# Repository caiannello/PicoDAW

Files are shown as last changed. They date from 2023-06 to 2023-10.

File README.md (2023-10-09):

# PicoDAW
A portable music sequencer and sampler based on Raspberry Pi Pico.  

WORK IN PROGRESS. 

There's no software yet! Also, I'm hoping that the SDIO SD Card interface is fast enough to stream
some audio tracks, since the Pico only has around 264KB or RAM. :D  We'll see.

I have code in the Pico and keyboard MCU to test the switches and LCD. Lots of diodes
need to be refitted, but progress is slowly being made. It is not yet able to make
any sounds.  

(Mockup screen borrowed from the MilkyTracker project. Just a static image..)
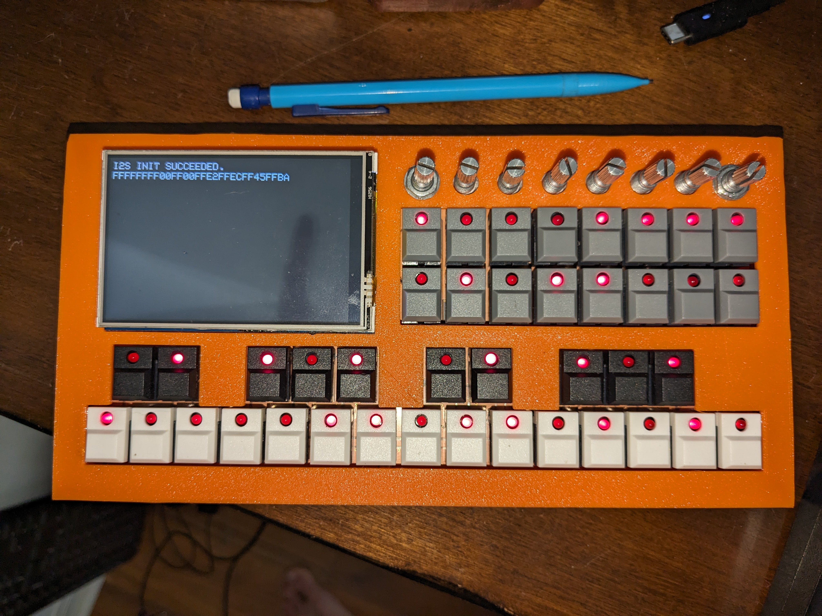
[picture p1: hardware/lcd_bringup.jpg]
LCD bring-up


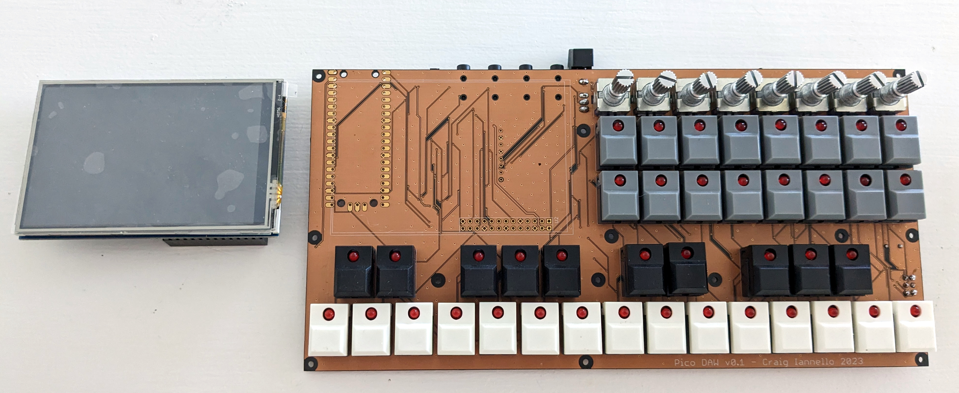
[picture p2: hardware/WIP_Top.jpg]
top

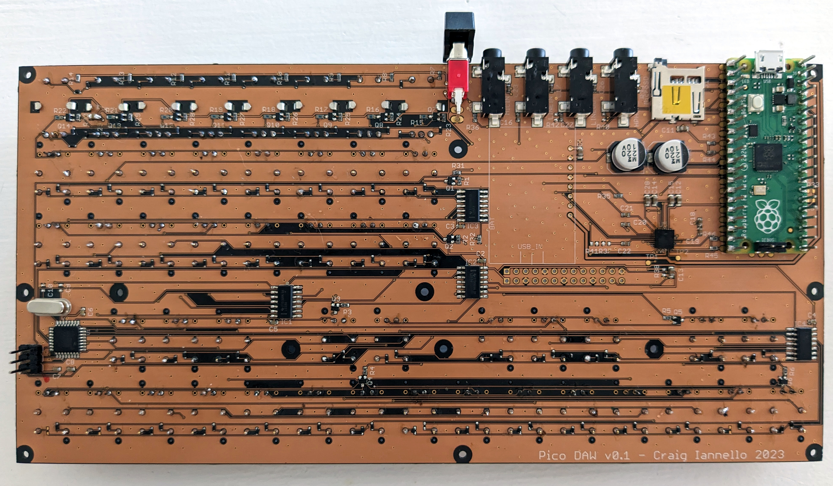
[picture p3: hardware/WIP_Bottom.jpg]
bottom


Velocity Sensitivity Note:

The keyswitches are quite clicky. They are HONYONE PB86 with integrated LED. Because the switches are SPDT Single-Pole-Double-Throw,
there is a possibility of timing the switch's break-before-make to get velocity information.  

That's why both throws on each switch are connected in the key matrix. 102 tiny little diodes.
During testing though, the clicky-ness of the keys causes this feature to not work very well. 

I tried anneling the switch's spring with heat, but that was a fail. 

Maybe someday I'll find some more suitable SPDT switches, but at least these ones look really cool!

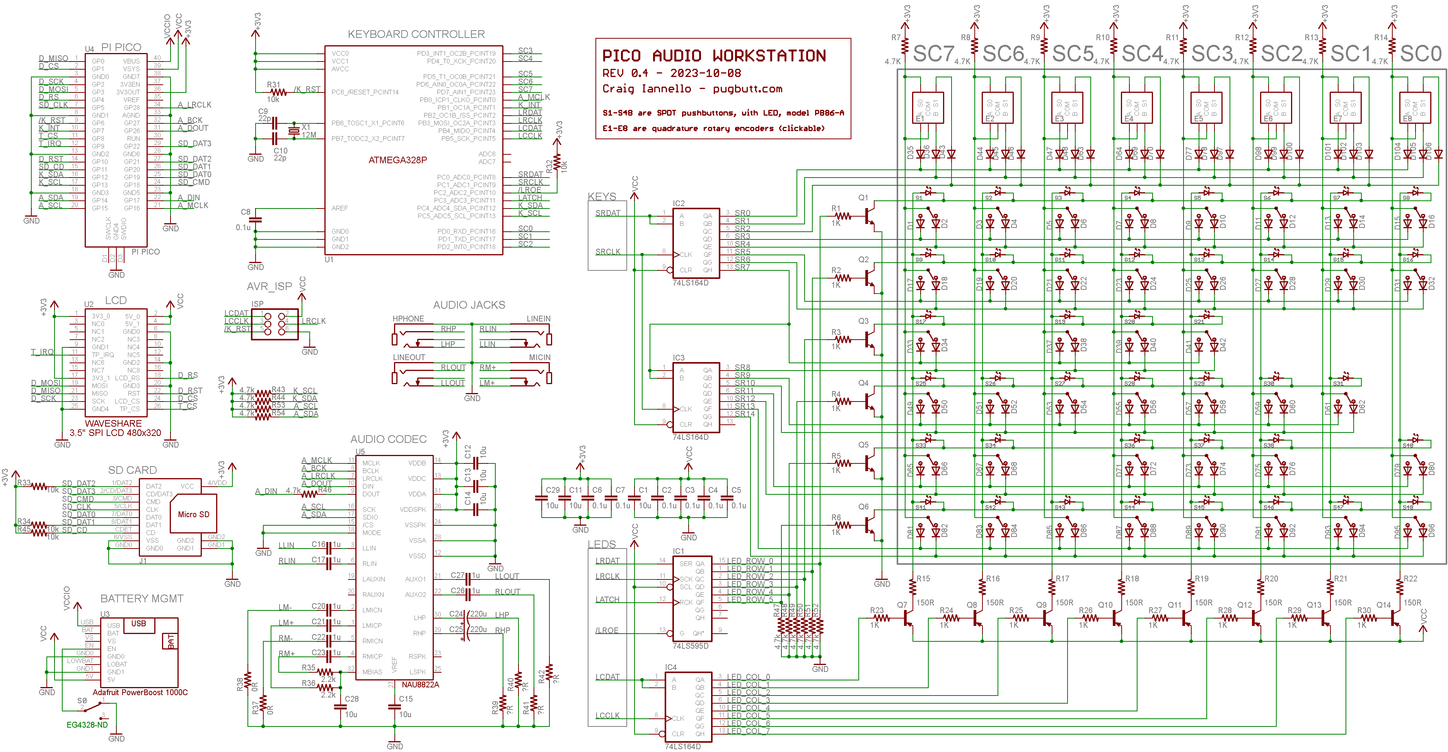
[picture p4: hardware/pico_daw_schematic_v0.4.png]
schematic

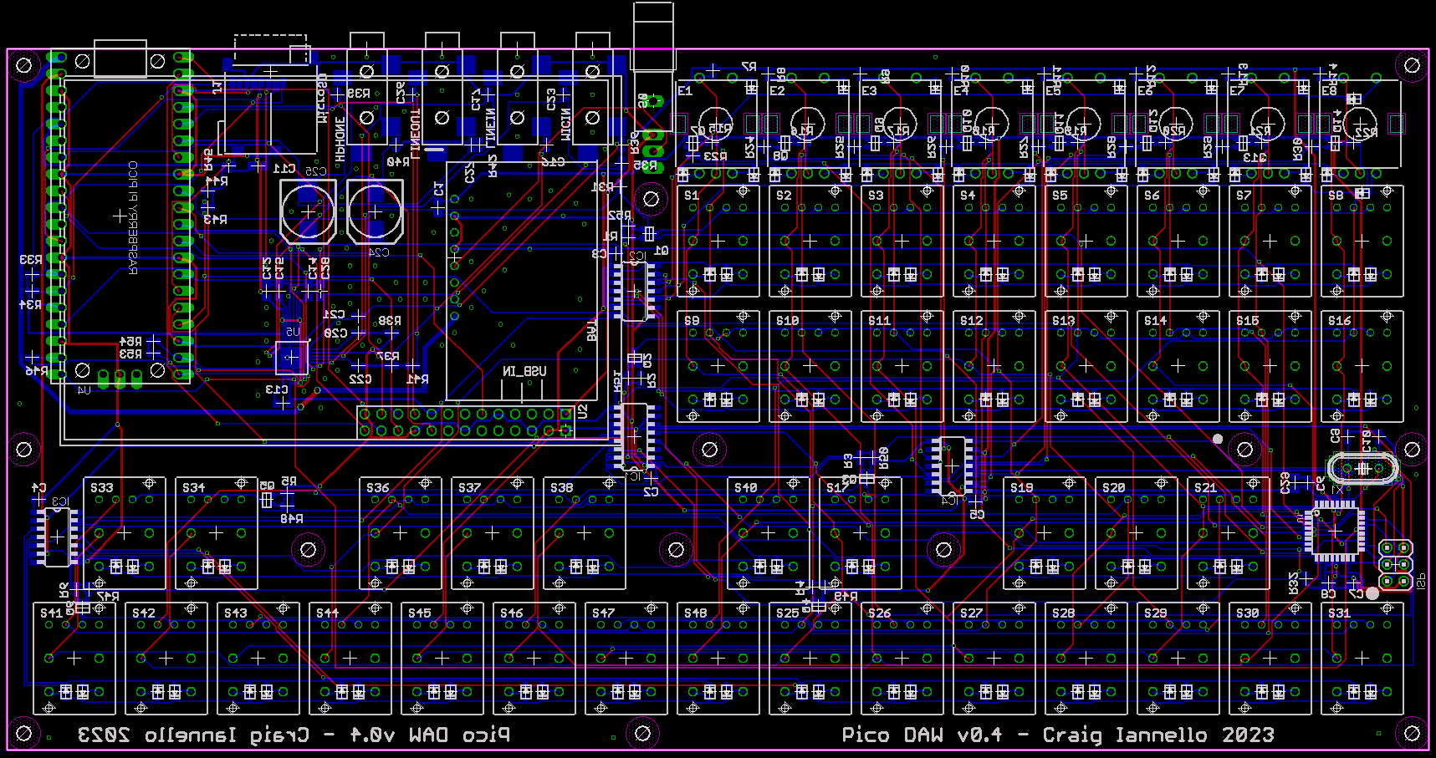
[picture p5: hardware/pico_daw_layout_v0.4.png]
layout


I've modelled a case and ordered it on Craftcloud.

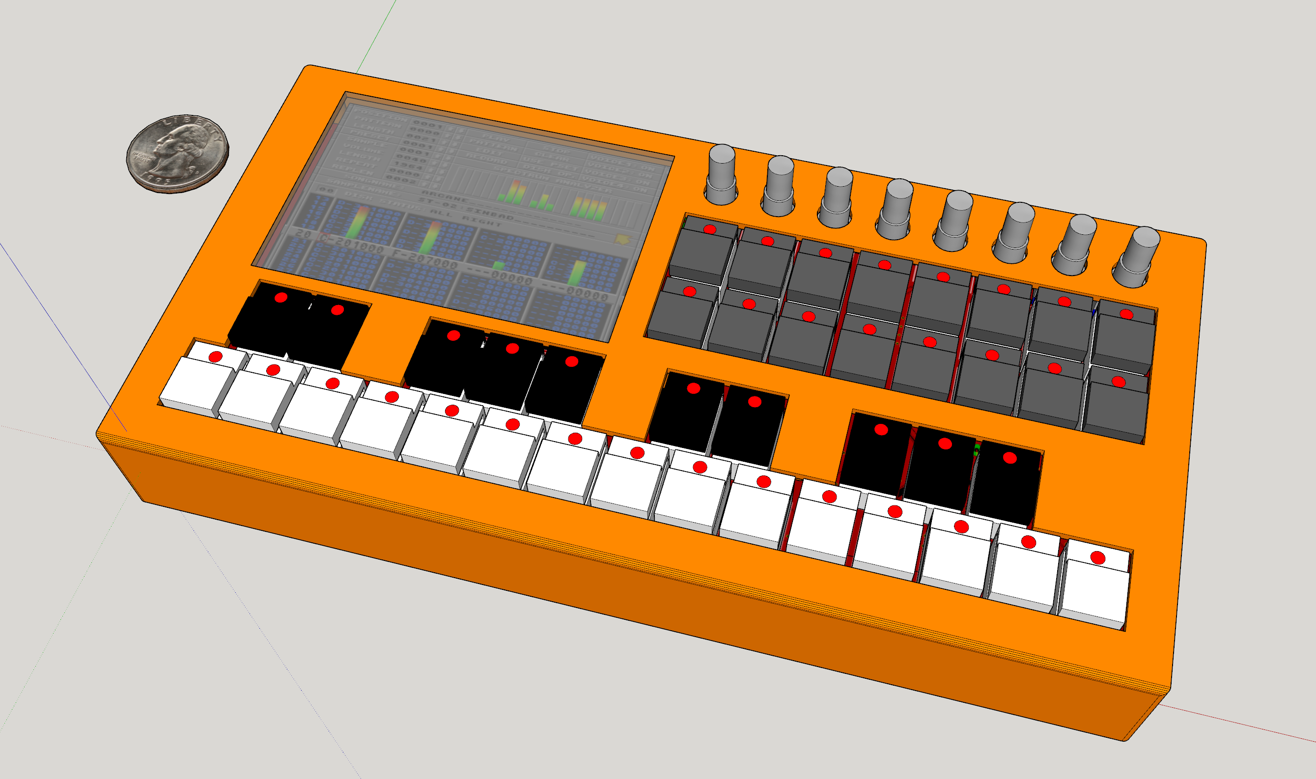
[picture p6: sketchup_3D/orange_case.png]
case design


Let's have an animated GIF on this page like its 1995!!

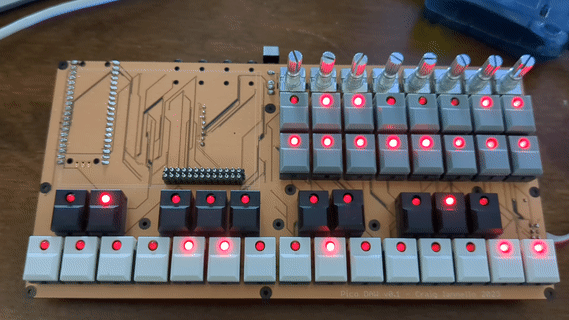
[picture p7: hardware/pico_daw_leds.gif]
blinky


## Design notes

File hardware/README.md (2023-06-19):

The schematic and board were made in Cadsoft EAGLE v4.16r2.

(I need to learn KiCAD someday.)

WARNING: TO PREVENT MAGIC SMOKE, REMOVE THE POWER DIODE FROM THE PI PICO !!!

This is because the battery board outputs it's own 5V, which runs to 
Vsys on the PI, and it and it receives its 5V charging voltage from the Pi's
Vusb.  (These two rails need to be decoupled on the Pi board.)

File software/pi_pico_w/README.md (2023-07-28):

So far, the Pi Pico code is just a switch / LCD test, with an attempt at a tone generator.

Note, this Arduino project uses the excellent gfx library, [TFT_eSPI, by Bodmer.](https://github.com/Bodmer/TFT_eSPI)

Before compiling, you have to customize one file of the library to reflect the GPIO connections to the LCD. (I tried defining them in my project, but I was unsuccessful.)

In "Arduino/libraries/TFT_eSPI-master/User_setup.h":
```
#define USER_SETUP_INFO "User_Setup"
#define RPI_ILI9486_DRIVER

#define TFT_SPI_PORT  0
#define TFT_MISO      0   // Automatically assigned with ESP8266 if not defined
#define TFT_MOSI      3   // Automatically assigned with ESP8266 if not defined
#define TFT_SCLK      2   // Automatically assigned with ESP8266 if not defined
#define TFT_CS        1   // Chip select control pin D8
#define TFT_DC        4   // Data Command control pin
#define TFT_RST       12  // Reset pin (could connect to NodeMCU RST, see next line)
#define TOUCH_CS      8   // Chip select pin (T_CS) of touch screen

#define SPI_FREQUENCY  27000000
#define SPI_READ_FREQUENCY  20000000
```
Note the 27MHz SPI clock speed. If you experience graphical glitches, try lowering that value.

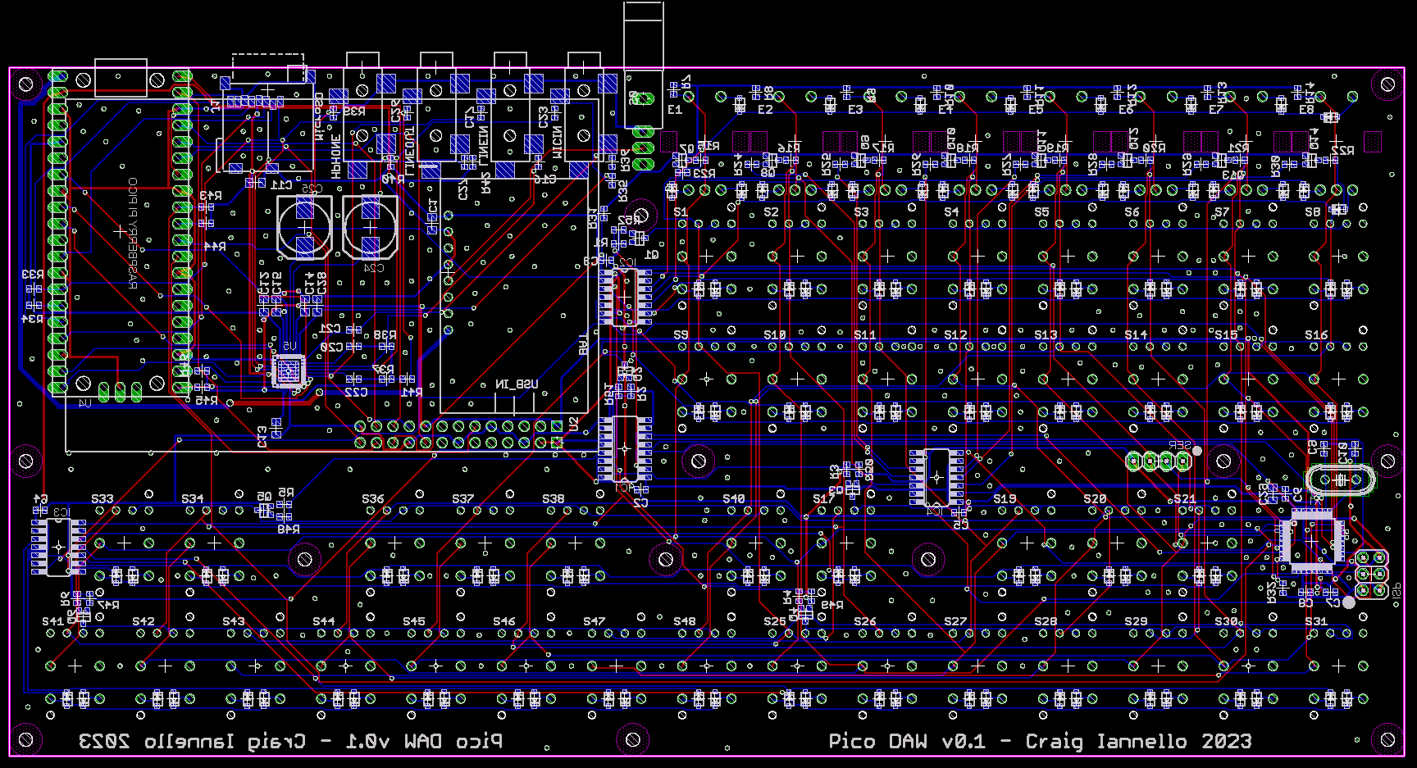
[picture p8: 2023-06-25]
hardware/pico_daw_layout_v0.1.png

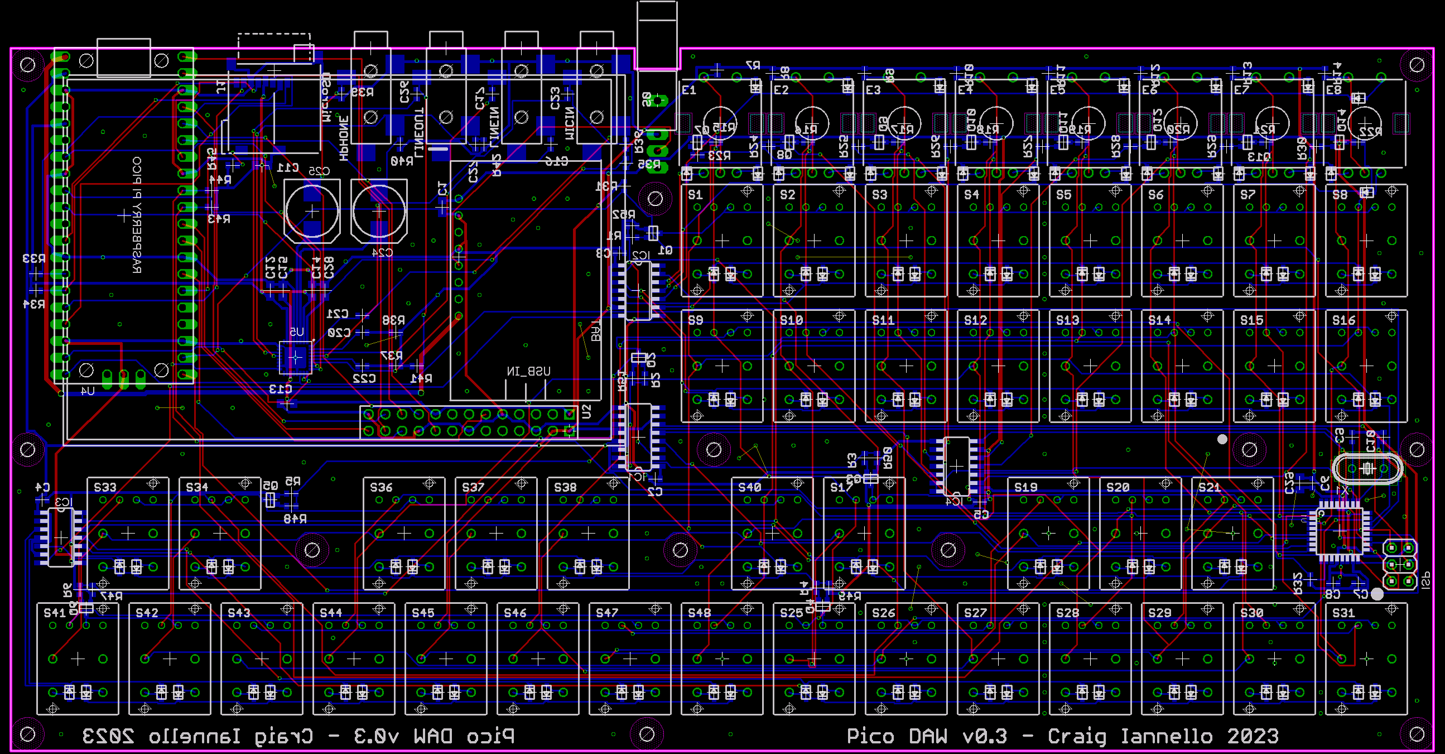
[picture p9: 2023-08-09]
hardware/pico_daw_layout_v0.3.png

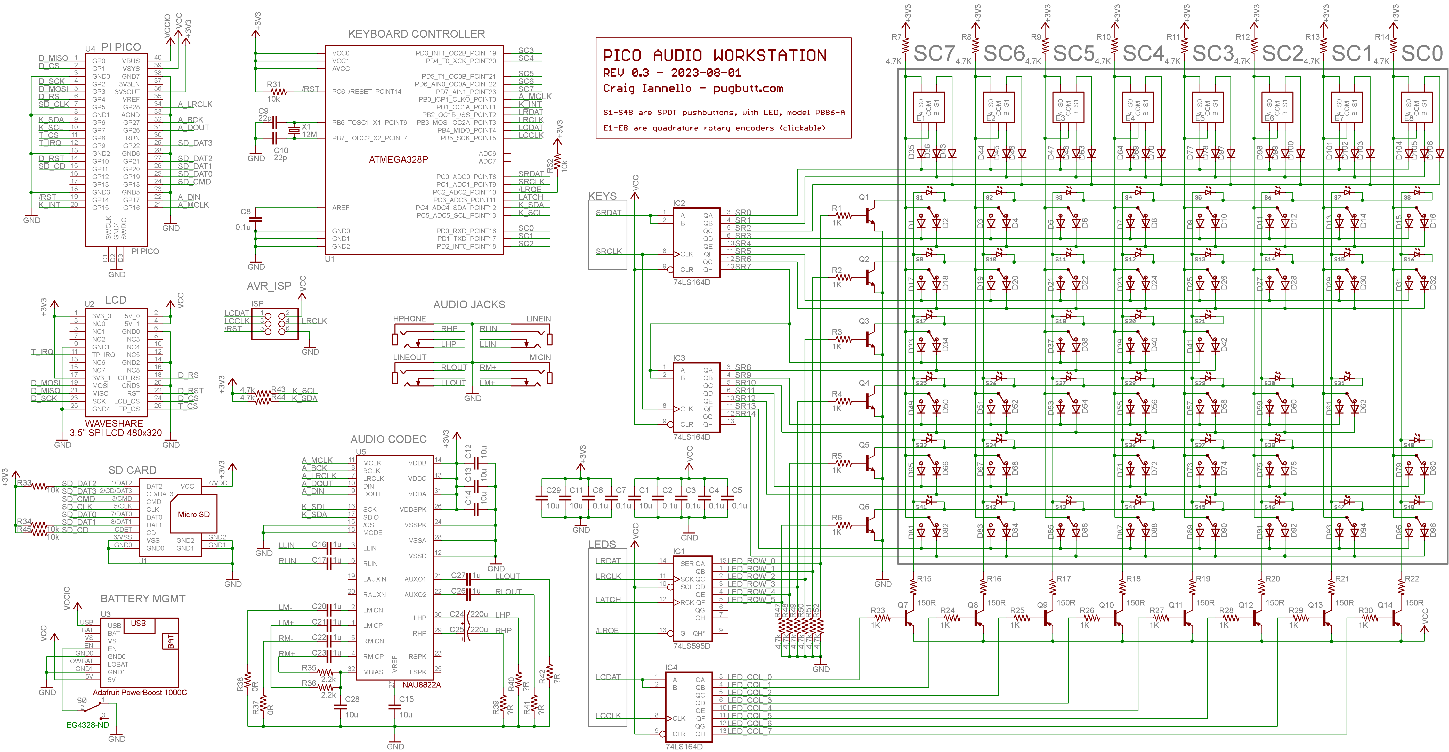
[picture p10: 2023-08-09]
hardware/pico_daw_schematic_v0.3.png

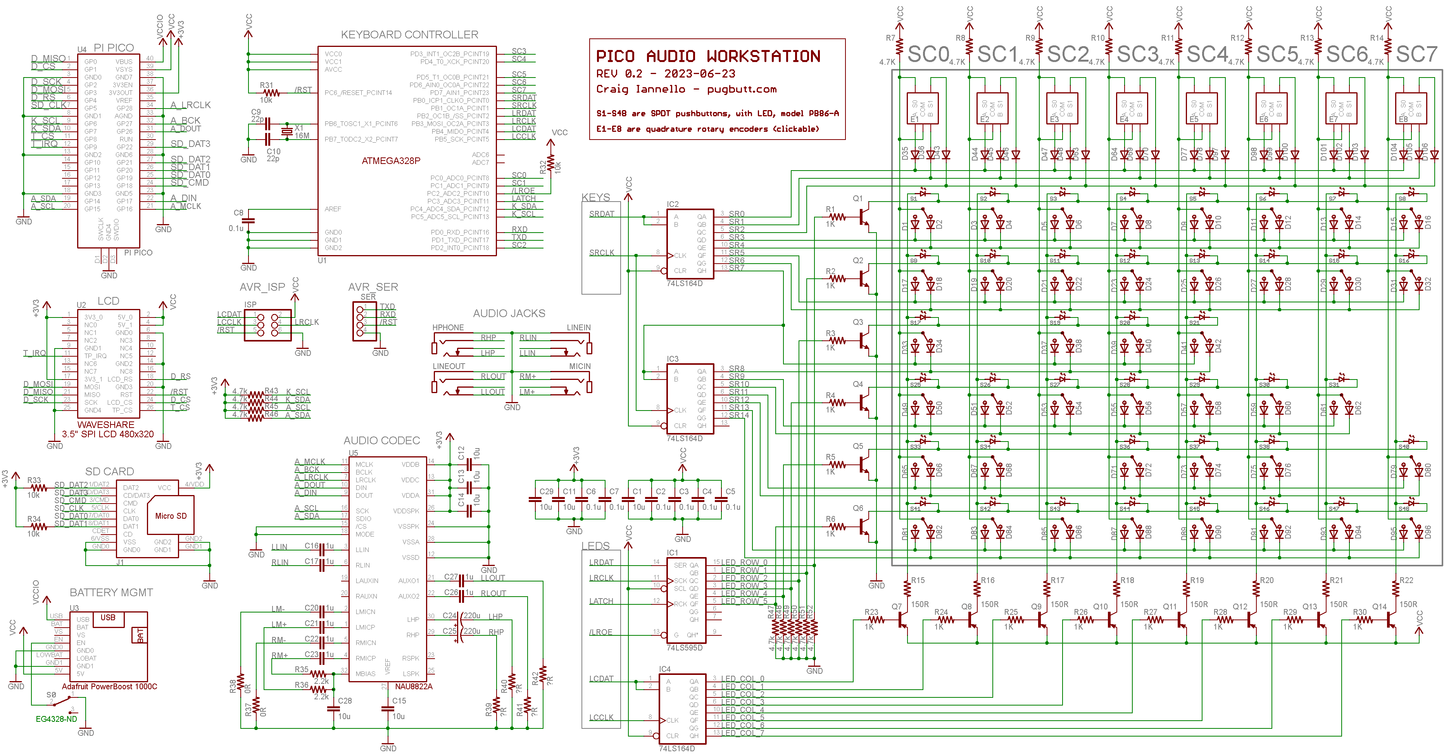
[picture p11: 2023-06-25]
hardware/pico_daw_schematic_v0.1.png

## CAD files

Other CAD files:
sketchup_3D/pico_daw_0.2.skp
sketchup_3D/pico_daw_0.3.skp
sketchup_3D/pico_daw_0.3_x_glitchy_sketchup.skp

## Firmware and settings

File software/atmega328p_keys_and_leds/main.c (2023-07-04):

///////////////////////////////////////////////////////////////////////////////
//
// atmega328p_keys_and_leds.c
//
// This is the firmware for the little ATMEGA328P MCU of the Pico DAW.
// It controls the LED's, reads the keyboard, and communicates with
// Pi Pico over an I2C interface.
//
// SWITCH MATRIX - PHYSICAL
//
// There's a row of eight click-able rotary encoders up top, and each
// contains three outputs: click, quadrature A, and quadrature B.
//
// Beneath the encoders are six rows of eight SPDT pushbuttons.
// Each button has one LED and two outputs: a normally-closed contact,
// and a normally-open contact.
//
// When a button is pressed or released, we can time the break-before-make
// between the two contacts to get an indication of velocity, though the
// clicky nature of these buttons distorts the results.
//
// Seven pushbuttons are left vacant in the design.
//
// SWITCH MATRIX AND LED MATRIX - ELECTRICAL
//
// The electrical switch matrix has fifteen rows of eight columns,
// accounting for all the outputs of the encoders and pushbuttons.
//
// Each device occupies one column of the matrix, and either three or
// two rows, respectively, for encoders or pushbuttons.
//
// The top three rows are for the encoders:
//
// Row 0: Encoder Quadrature A
// Row 1: Encoder Quadrature B
// Row 2: Encoder Click
//
// The remaining twelve rows are for the pushbuttons:
//
// Row 3: Pushbutton row 0 contact, Normally-Open
// Row 4: Pushbutton row 0 contact, Normally-Closed
// ...
// Row 13: Pushbutton row 5 contact, Normally-Open
// Row 14: Pushbutton row 5 contact, Normally-Closed
//
// Each button has an LED, so there is also a LED matrix which is
// electrically distinct from the switch matrix. It is six rows
// by eight columns.
//
// MATRIX INTERFACE
//
// A naive approach for hooking both the matrices up to an MCU might
// to to hook each row and column to a GPIO on the MCU, but there are
// 37 of them! We don't have that many pins to spare.
//
// One alternative is to use an IC called a 74LS164D, which is a
// serial-in, parallel-out shift register. It has two inputs,
// clock and data, and eight outputs. You can clock eight bits into
// the chip to set the state of outputs, using only two GPIO pins.
//
// These chips can also be cascaded to add more outputs without
// needing any more GPIO's.
//
// Two of these chips are cascaded to allow the MCU to select which
// of the 15 switch rows to read. A row is selected by outputting
// a zero state (0 Volts) on that row, and one states (5V) on all
// the other rows.
//
// Each column is hooked up to a GPIO input, and reading them
// will let us determine the state of the switches in the selected
// row. (Open switches will read one, and closed switches will read
// zero.)
//
// On startup, the row selection is initialized by clocking in sixteen
// ones, followed by a single zero. This selects the first switch row.
//
// Fifteen times, we read PORTD and then clock in a one, which shifts
// that zero bit down to select the next row.
//
// After all fifteen rows have been read, we clock in a single zero,
// which shifts that old zero out of the top of the register and
// selects the first row again.
//
// The circuitry for the LED matrix is similar, but now one shift
// register selects LED row, and another shift register sets the
// state of all the columns of the selected row. The column-select
// is the same 74LS164D as was used on the switch matrix, but the
// row select is a slightly different chip: It is a 74LS595D, which
// adds two inputs: latch-enable and output-enable. This is so we
// can turn off the output-enable (turning off all LEDs) whenever
// new column data is shifted in, so OFF LEDs wont be seen dimly
// flickering during the update process.
//
// We want to scan the key matrix quickly to allow velocity measurement,
// but we can update the LED matrix much slower: one LED row for every full
// scan of the KB, or all LED rows will be updated every six KB scans.
//
// As keyboard events occur, we queue them for output to the main CPU,
// a Raspberry Pi Pico-W. The interface is a two-wire I2C bus.
//
// As keyboard events go out to the Pico, LED state changes come back in.
//
// Created: 6/19/2023 9:52:17 PM
// Author : Craig Iannello  www.pugbutt.com
//
///////////////////////////////////////////////////////////////////////////////
#include <avr/io.h>
#include <avr/interrupt.h>
#include "TWI_Master.h"
// ----------------------------------------------------------------------------
#define MAIN_CPU_HZ     8000000.0
#define KB_FULLSCAN_HZ  1000.0    // (333 Hz LED update rate)
// ----------------------------------------------------------------------------
uint8_t sw_states[16];
uint8_t led_states[6];
uint8_t cur_led_row = 0;  // current led row for refresh
unsigned char TWI_targetSlaveAddress = 0x30;
// ----------------------------------------------------------------------------
// timer ISR sets this flag to tell main-loop to scan the key matrix again
// ----------------------------------------------------------------------------
volatile uint8_t kb_scan_flag = 0;
// ----------------------------------------------------------------------------
// Setup the GPIO pins, event timer(s), and I2C communications.
// ----------------------------------------------------------------------------
void init(void)
{
  // Setup GPIO pins.

  // PORTB: 7: NC,          6: NC,          5: LED_COL_CLK, 4: LED_COL_DAT,
  //        3: LED_ROW_CLK, 2: LED_ROW_DAT, 1: SW_ROW_CLK,  0: SW_ROW_DAT
  DDRB  = 0b00111111;
  PORTB = 0b11111111;
  // PORTC: 7: NC,          6: NC,          5: I2C_SCL,     4: I2C_SDA,
  //        3: NC,          2: NC,          1: NC,          0: SHIFTREGS_RESET
  DDRC  = 0b00000001;
  PORTC = 0b11001111;
  // PORTD: 7: SW_COL_7,    6: SW_COL_6,    5: SW_COL_5,    4: SW_COL_4,
  //        3: SW_COL_3,    2: SW_COL_2,    1: SW_COL_1,    0: SW_COL_0
  DDRD  = 0b00000000;
  PORTD = 0b00000000;

  // disable interrupts
  cli();
  // timer 0 : Each rollover starts a full scan of the key matrix
  // and updates 1 of the 6 LED rows
  // timer 0 - Fast PWM, rollover at TOP (OCR0A) , prescaler: clk/256
  TCCR0A = 0x03;
  TCCR0B = 0x0C;
  // timer 0 - set TOP value for desired rollover rate
  OCR0A = MAIN_CPU_HZ / 256.0 / KB_FULLSCAN_HZ;
  // enable timer 0 rollover interrupt
  TIMSK0 = 0x01;

  // Setup our main output interface (i2c) to the Pi Pico W (main) CPU.
  TWI_Master_Initialise();

  // enable interrupts
  sei();
}
// ----------------------------------------------------------------------------
ISR (TIMER0_OVF_vect)
{
  kb_scan_flag = 1;
}
// ----------------------------------------------------------------------------
// Initialize the state of all shift registers.
// Selects the first row each of both the switch and the LED matrices.
// ----------------------------------------------------------------------------
inline void regs_reset(void)
{
  // De-select all switch rows, all led rows, and all LED columns
  PORTB |=  0x11;  // LED_COL_DAT = 1, SW_ROW_DAT = 1
  PORTB &= ~0x04;  // LED_ROW_DAT = 0
  for (uint8_t i=0;i<16;i++)
  {
    PORTB &= ~0x2A; // start clock pulses on led row, sw row, and sw col
    PORTB |=  0x2A; // end clock pulses
  }
  // clock a single 0 into the sw row reg to select the first sw row,
  // and clock a single 1 into the led row reg to select the first led row
  PORTB &= 0xFE;  // SW_ROW_DAT = 0
  PORTB |= 0x04;  // LED_ROW_DAT = 1
  PORTB &= ~0x0A; // LED_ROW_CLK = 0, SW_ROW_CLK = 0
  PORTB |= 0x0A;  // LED_ROW_CLK = 1, SW_ROW_CLK = 1
  PORTB &= ~0x04; // LED_ROW_DAT = 0
  PORTB |= 0x01;  // SW_ROW_DAT = 1
}
// ----------------------------------------------------------------------------
// resets all shift regs to 0's - not really very useful
// ----------------------------------------------------------------------------
inline void regs_clear(void)
{
  PORTC &= 0xFE; // start reset pulse
  PORTC |= 0x01; // end reset pulse
}
// ----------------------------------------------------------------------------
// Shifts 8 bits into the LED columns register. Bits which are set will cause
// the corresponding LED to be lit on the currently selected row.
// ----------------------------------------------------------------------------
inline void set_led_row(uint8_t cols)
{
  for(uint8_t i=0;i<8;i++)
  {
    PORTB &= ~0x10;    // LED_COL_DAT = 0
    if(!(cols&1))
      PORTB|= 0x10;   // LED_COL_DAT = NOT cols.LSB
    // clock the bit value into the cols register
    PORTB &= ~0x20;   // LED_COL_CLK = 0
    PORTB |= 0x20;    // LED_COL_CLK = 1
    cols>>=1;         // select next bit of cols value
  }
}
// ----------------------------------------------------------------------------
inline void refresh_led_row(void)
{
  set_led_row(led_states[cur_led_row]);
  cur_led_row++;
  if(cur_led_row == 6) // if finished all LED rows
  {
    // reselect first row of leds
    cur_led_row = 0;
    PORTB |= 0x04;  // LED_ROW_DAT = 1
    PORTB &= ~0x08; // LED_ROW_CLK = 0
    PORTB |= 0x08;  // LED_ROW_CLK = 1
    // don't select more than one LED row at a time
    PORTB &= ~0x04; // LED_ROW_DAT = 0
  } else  // still have led rows left to update
  {
    // select next led row
    PORTB &= ~0x08; // LED_ROW_CLK = 0
    PORTB |= 0x08;  // LED_ROW_CLK = 1
  }
}
// ----------------------------------------------------------------------------
// begins a full scan of the keyboard matrix
// ----------------------------------------------------------------------------
inline void scan_kb(void)
{
  // sample all 15 switch rows
  for(uint8_t row=0;row<15;row++)
  {
    uint8_t b = PIND;
    sw_states[row+1] = b;  // read the eight columns of the switch row
    PORTB &= ~0x02; // SW_ROW_CLK = 0
    PORTB |= 0x02;  // SW_ROW_CLK = 1
  }
  sw_states[0] = TWI_targetSlaveAddress << 1;
  TWI_Start_Transceiver_With_Data( sw_states, 16 );
  // re-select first switch row
  PORTB &= ~0x01; // SW_ROW_DAT = 0
  PORTB &= ~0x02; // SW_ROW_CLK = 0
  PORTB |= 0x02;  // SW_ROW_CLK = 1
  PORTB |= 0x01;  // SW_ROW_DAT = 1
}
// ----------------------------------------------------------------------------
// indicate error state by forever animating first row of LEDs
// ----------------------------------------------------------------------------
void do_guru_meditation()
{
  uint16_t guru_ticks=0;
  uint8_t v = 0x80;
  regs_reset();
  while(1)
  {
    if(kb_scan_flag)
    {
      kb_scan_flag=0;
      if(++guru_ticks > 40)
      {
        guru_ticks = 0;
        set_led_row(v);
        v>>=1;
        if(v==0)
          v=0x80;
      }
    }
  }
}
// ----------------------------------------------------------------------------
int main(void)
{
    uint8_t rows = 0;
    init();       // init MCU IO and timers
    regs_clear();
    regs_reset(); // select first switch row and first LED row
    while (1)     // begin main-loop
    {
      if(kb_scan_flag)
      {
        kb_scan_flag = 0;
        refresh_led_row();
        scan_kb();
        if(++rows==12)
        {
          rows=0;
          led_states[rand()%6] = rand()%256;
        }
        if(kb_scan_flag)  // too slow! go into guru meditation mode
        {
          do_guru_meditation();
        }
      }           // finished a scan of the keyboard
    }             // end main-loop
}
///////////////////////////////////////////////////////////////////////////////
// EOF
///////////////////////////////////////////////////////////////////////////////

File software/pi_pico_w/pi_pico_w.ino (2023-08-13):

#include <SPI.h>
#include <TFT_eSPI.h>
#include <Wire.h>
#include <I2S.h>
#include "hardware/pwm.h"
#include "defines.h"
#include "mock_screen.h"

static char buff[100];
static char codec_i2c_buff[100];

TFT_eSPI tft = TFT_eSPI();       // Invoke custom library

volatile uint8_t last_len = 0;
volatile uint8_t codec_i2c_last_len = 0;

// Create the I2S port using a PIO state machine
I2S i2s(OUTPUT);

/*
void I2S_EnableMCLK(unsigned long rate_hz)
{
  // output 12MHz on pMCLK
 //  vreg_set_voltage(VREG_VOLTAGE_1_30);

	gpio_set_function(pMCLK, GPIO_FUNC_PWM);	
	uint osc_slice = pwm_gpio_to_slice_num(pMCLK);
	pwm_set_clkdiv_int_frac(osc_slice, 1, 0);
	pwm_set_wrap(osc_slice, 2);
	pwm_set_chan_level(osc_slice, pwm_gpio_to_channel(pMCLK), 1);
	pwm_set_enabled(osc_slice, true);  
}
*/

void I2C_WriteWAU8822(uint8_t u8addr, uint16_t u16data) 
{
  Wire1.beginTransmission(NAU8822_I2C_ADDRESS);
  Wire1.write(u8addr<<1);
  Wire1.write((uint8_t)((u8addr << 1) | (u16data >> 8)));
  Wire1.write((uint8_t)(u16data & 0x00FF));
  Wire1.endTransmission();
}

uint16_t I2C_ReadWAU8822(uint8_t u8addr) 
{
  uint16_t res = 0;
  Wire1.beginTransmission(NAU8822_I2C_ADDRESS);
  Wire1.write(u8addr<<1);
  Wire1.requestFrom(NAU8822_I2C_ADDRESS,2,true);
  res=Wire1.read();
  res<<=8;
  res|=Wire1.read();
  Wire1.endTransmission();
  return res;
}

void WAU8822_ConfigSampleRate(uint32_t u32SampleRate)
{
    if((u32SampleRate % 8) == 0)
    {
        I2C_WriteWAU8822(36, 0x008);    //12.288Mhz
        I2C_WriteWAU8822(37, 0x00C);
        I2C_WriteWAU8822(38, 0x093);
        I2C_WriteWAU8822(39, 0x0E9);
    }
    else
    {
        I2C_WriteWAU8822(36, 0x007);    //11.2896Mhz
        I2C_WriteWAU8822(37, 0x021);
        I2C_WriteWAU8822(38, 0x131);
        I2C_WriteWAU8822(39, 0x026);
    }

    switch (u32SampleRate)
    {
    case 16000:
        I2C_WriteWAU8822(6, 0x1AD);   /* Divide by 6, 16K */
        I2C_WriteWAU8822(7, 0x006);   /* 16K for internal filter coefficients */
        break;

    case 32000:
        I2C_WriteWAU8822(6, 0x16D);    /* Divide by 3, 32K */
        I2C_WriteWAU8822(7, 0x002);    /* 32K for internal filter coefficients */
        break;

    case 44100:
    case 48000:
        I2C_WriteWAU8822(6, 0x14D);    /* Divide by 1, 48K */
        I2C_WriteWAU8822(7, 0x000);    /* 48K for internal filter coefficients */
        break;
    }
}

void Delay(int count)
{
    volatile uint32_t i;
    for (i = 0; i < count ; i++);
}

void setup()   
{
  tft.init();
  tft.setRotation(1);
  tft.fillScreen(TFT_BLACK);
  tft.setTextSize(1);
  tft.setTextColor(TFT_WHITE);
  tft.setCursor(0, 0);

  pinMode(LED_BUILTIN, OUTPUT);
  digitalWrite(LED_BUILTIN, 1);

  Serial.begin(115200);
  Serial.println("I2S simple tone");

  // kb controller i2c
  pinMode(kSDA,INPUT);
  pinMode(kSCL,INPUT);
  Wire.onReceive(recv);
  Wire.onRequest(req);
  Wire.setSDA(kSDA);
  Wire.setSCL(kSCL);
  Wire.begin(0x30);

  // audio codec i2c
  pinMode(pSDA,INPUT);
  pinMode(pSCL,INPUT);
  Wire1.setSDA(pSDA);
  Wire1.setSCL(pSCL);
  Wire1.setClock(100000);
  Wire1.begin();

  // audio codec init 
  I2C_WriteWAU8822(0,  0x000);   // Reset all registers 
  Delay(0x200);
  I2C_WriteWAU8822(1,  0x02F);
  I2C_WriteWAU8822(2,  0x1B3);   // Enable L/R Headphone, ADC Mix/Boost, ADC 
  I2C_WriteWAU8822(3,  0x07F);   // Enable L/R main mixer, DAC 
  // offset: 0x4 => default, 24bit, I2S format, Stereo
  I2C_WriteWAU8822(4,  0x010);   // 16-bit word length, I2S format, Stereo 

  I2C_WriteWAU8822(5,  0x000);   // Companding control and loop back mode (all disable) 
  I2C_WriteWAU8822(6,  0x1AD);   // Divide by 6, 16K 
  I2C_WriteWAU8822(7,  0x006);   // 16K for internal filter coefficients 
  I2C_WriteWAU8822(10, 0x008);   // DAC soft mute is disabled, DAC oversampling rate is 128x 
  I2C_WriteWAU8822(14, 0x108);   // ADC HP filter is disabled, ADC oversampling rate is 128x 
  I2C_WriteWAU8822(15, 0x1EF);   // ADC left digital volume control 
  I2C_WriteWAU8822(16, 0x1EF);   // ADC right digital volume control 

  I2C_WriteWAU8822(44, 0x000);   // LLIN/RLIN is not connected to PGA 
  I2C_WriteWAU8822(47, 0x050);   // LLIN connected, and its Gain value 
  I2C_WriteWAU8822(48, 0x050);   // RLIN connected, and its Gain value 
  I2C_WriteWAU8822(50, 0x001);   // Left DAC connected to LMIX 
  I2C_WriteWAU8822(51, 0x001);   // Right DAC connected to RMIX 
  
  // Set MCLK and enable MCLK 
  //I2S_EnableMCLK(12000000);
  WAU8822_ConfigSampleRate(SAMPLE_RATE_HZ);
  
  tft.setTextSize(2);
  tft.setCursor(0, 5);

  // start I2S at the sample rate with 16-bits per sample
  i2s.setMCLK(pMCLK);
  i2s.setMCLKmult(256);
  i2s.setBCLK(pBCLK);
  i2s.setDATA(pDOUT);
  i2s.setBitsPerSample(16);
  i2s.setBuffers(2, 256, 0);

  if (!i2s.begin(SAMPLE_RATE_HZ)) 
  {
    Serial.println("Failed to initialize I2S!");
    tft.setTextColor(TFT_VFD_ORANGE);
    tft.print("I2S INIT FAILED!!!");
    while (1); // do nothing
  }
  tft.print("I2S INIT SUCCEEDED.");
  digitalWrite(LED_BUILTIN, 0);

}

// Called when the I2C slave gets written to
void recv(int len) 
{
    for (int i=0; i<len; i++) buff[i] = Wire.read();
    last_len = len;
}


// Called when the I2C slave is read from
void req() 
{
    static int ctr = 765;
    char buff[7];
    // Return a simple incrementing hex value
    sprintf(buff, "%06X", (ctr++) % 65535);
    Wire.write(buff, 6);
}

void draw_mockup(void)
{
  uint16_t *p = (uint16_t *)(gimp_image.pixel_data);
  for(int y=0;y<320;y++)
  for(int x=0;x<480;x++)
  {
    tft.drawFastHLine(x, y, 1, *p);
    p++;
  }  
}

void switch_test(void)
{
  draw_mockup();

  for(int y=20;y<42;y++)
    tft.drawFastHLine(0, y, 480, 0);
  
  tft.setTextSize(2);
  char s[6];
  char lineout[40]="";
  char oldlineout[40]="";
  while(1)
  {
    lineout[0]=0;
    for(int i=0;i<15;i++)
    {
      sprintf(s,"%02X",buff[i]);
      strcat(lineout,s);
    }
    uint16_t rval = I2C_ReadWAU8822(36);
    sprintf(s," %04X",buff[rval]);
    strcat(lineout,s);


    if(strcmp(lineout,oldlineout))
    {
      tft.setCursor(0, 25);
      tft.setTextColor(TFT_BLACK);
      tft.print(oldlineout);

      tft.setCursor(0, 25);
      tft.setTextColor(TFT_VFD_BLUWHT);//TFT_VFD_ORANGE);
      tft.print(lineout);
      strcpy(oldlineout,lineout);

    }
  }  
}

void codec_test(void)
{
  tft.setTextSize(2);
  tft.setCursor(0, 25);
  tft.setTextColor(TFT_VFD_BLUWHT);//TFT_VFD_ORANGE);
  tft.print("I hope she's making some noise!!!");
  while(1)
  {
      i2s.write16(rand()%65536,rand()%65536);
  };
}

void loop() 
{
  switch_test();
  //codec_test();
}
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

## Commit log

2023-06-19 Eagle 4.16 schematic and layout
    [ordered_nobrain_416.brd, ordered_nobrain_416.sch]
2023-06-24 board update shiftregs, bigger diodes, led test
    [nobrain_v0.2.brd, nobrain_v0.2.sch]
2023-06-24 schematic updates
    [nobrain_v0.2.brd, nobrain_v0.2.sch]
2023-06-24 board ground fill
    [nobrain_v0.2.brd, nobrain_v0.2.sch]
2023-06-24 mcu ground fill
    [nobrain_v0.2.brd, nobrain_v0.2.sch]
2023-06-24 remv i2s bus resistors
    [nobrain_v0.2.brd, nobrain_v0.2.sch]
2023-06-25 sw and ground pour
    [nobrain_v0.2.brd]
2023-06-25 img upd
    [nobrain_v0.2.sch]
2023-06-29 expand codec pack for easier alignment, connect d_rst
    [nobrain_v0.2.brd, nobrain_v0.2.sch]
2023-06-29 via madness
    [nobrain_v0.2.brd]
2023-07-03 swapped kb i2c lines oops
    [nobrain_v0.2.brd, nobrain_v0.2.sch]
2023-07-03 remv old version
    [ordered_nobrain_416.brd, ordered_nobrain_416.sch]
2023-07-04 via madness
    [nobrain_v0.2.brd]
2023-07-04 more intuitive ordering of switch matrix cols
    [nobrain_v0.2.brd, nobrain_v0.2.sch]
2023-07-04 via obsession
    [nobrain_v0.2.brd]
2023-07-05 sensible via stitching
    [nobrain_v0.2.brd, nobrain_v0.2.sch]
2023-07-05 vias vias everywhere
    [nobrain_v0.2.brd]
2023-07-27 case design
    [nobrain_v0.2.brd, pico_daw_0.2.skp]
2023-07-27 initial pi pico code
    just a switch test, an lcd driver, and a failing attempt at getting the audio codec to play a tone.
    [pi_pico_w.ino]
2023-08-02 new board rev, avr gen mclk, unified i2c
    [pico_daw_v0.3.brd, pico_daw_v0.3.sch]
2023-08-05 enlarge pcb mounting holes
    [pico_daw_0.2.skp, pico_daw_v0.3.brd]
2023-08-07 3d power switch clearance
    [pico_daw_0.2.skp]
2023-08-07 Still need to move pw switch ~1/8" further from board edge
    [pico_daw_v0.3.brd]
2023-08-07 recess power switch, allow pi pico to reset avr (for avr firmware upgrade via pico)
    [pico_daw_v0.3.brd, pico_daw_v0.3.sch]
2023-08-07 3d widen SD card slot
    [pico_daw_0.2.skp]
2023-08-09 uniform font on schematic
    [pico_daw_v0.3.sch]
2023-08-09 connect SD card-detect signal to pico
    [pico_daw_v0.3.brd, pico_daw_v0.3.sch]
2023-08-09 Ground-fill indicate cutout for pwr switch
    [pico_daw_v0.3.brd, pico_daw_v0.3.sch]
2023-08-12 widen usb hole, display window, thinner display cover glass
    [pico_daw_0.2.skp]
2023-08-12 new case, some edges rounded
    [pico_daw_0.2.skp, pico_daw_0.3.skp]
2023-08-13 working on i2c comms with codec
2023-10-09 rework I2C lines
    [pico_daw_0.3_x_glitchy_sketchup.skp, pico_daw_v0.4.brd, pico_daw_v0.4.sch]
2023-10-09 case image
    [pico_daw_0.3_x_glitchy_sketchup.skp]

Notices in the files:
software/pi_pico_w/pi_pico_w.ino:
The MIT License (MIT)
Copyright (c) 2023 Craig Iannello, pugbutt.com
